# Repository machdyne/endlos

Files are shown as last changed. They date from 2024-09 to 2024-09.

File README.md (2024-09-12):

# Endlos Computer

Endlos is a 1-layer FPGA computer designed by Lone Dynamics Corporation.

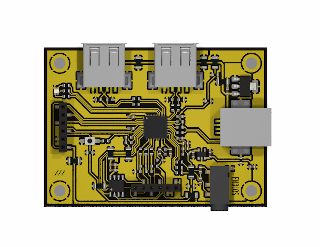
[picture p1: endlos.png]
Endlos Computer


This repo contains schematics, PCB layouts, pinouts, example gateware and documentation.

Find more information on the [Endlos product page](https://machdyne.com/product/endlos-computer/).

## Blinky 

Building the blinky example requires [Yosys](https://github.com/YosysHQ/yosys), [nextpnr-ice40](https://github.com/YosysHQ/nextpnr) and [IceStorm](https://github.com/YosysHQ/icestorm).

## Pinouts

### PMOD Socket (left, pins top-to-bottom)

| Pin | Signal | Description |
| ----| --- | --- |
| 1 | PMOD\_A1 | GPIO |
| 2 | PMOD\_A2 | GPIO |
| 3 | PMOD\_A3 | GPIO |
| 4 | PMOD\_A4 | GPIO |
| 5 | GND | Ground |
| 6 | 3V3 | Power |

### MMOD Socket (bottom, pins left-to-right)

| Pin | Signal | Description |
| --- | --- | --- |
| 1 | CSPI\_SS | GPIO |
| 2 | CSPI\_SO | GPIO |
| 3 | CSPI\_SI | GPIO |
| 4 | CSPI\_SCK | GPIO |
| 5 | GND | Ground |
| 6 | 3V3 | Power |

### Audio/Video Jack

| Pin | Description |
| --- | --- |
| T | Mono Audio |
| R1 | Mono Audio |
| R2 | Video |
| S | Ground |

## Board Revisions

| Revision | Notes |
| --- | ----- |
| V0 | Initial version |

Note #1: All of the functionality hasn't been tested yet, only configuration from MMOD and blinky on an LED PMOD.

Note #2: There should probably be a 10K pull-up on RAM\_SS, but configuration appears to work without it.

Note #3: Kapton tape is recommended under front of the USB-B connector.

## License

The contents of this repo are released under the [Lone Dynamics Open License](LICENSE.md).

Note: You can use these designs for commercial purposes but we ask that instead of producing exact clones, that you either replace our trademarks and logos with your own or add your own next to ours.

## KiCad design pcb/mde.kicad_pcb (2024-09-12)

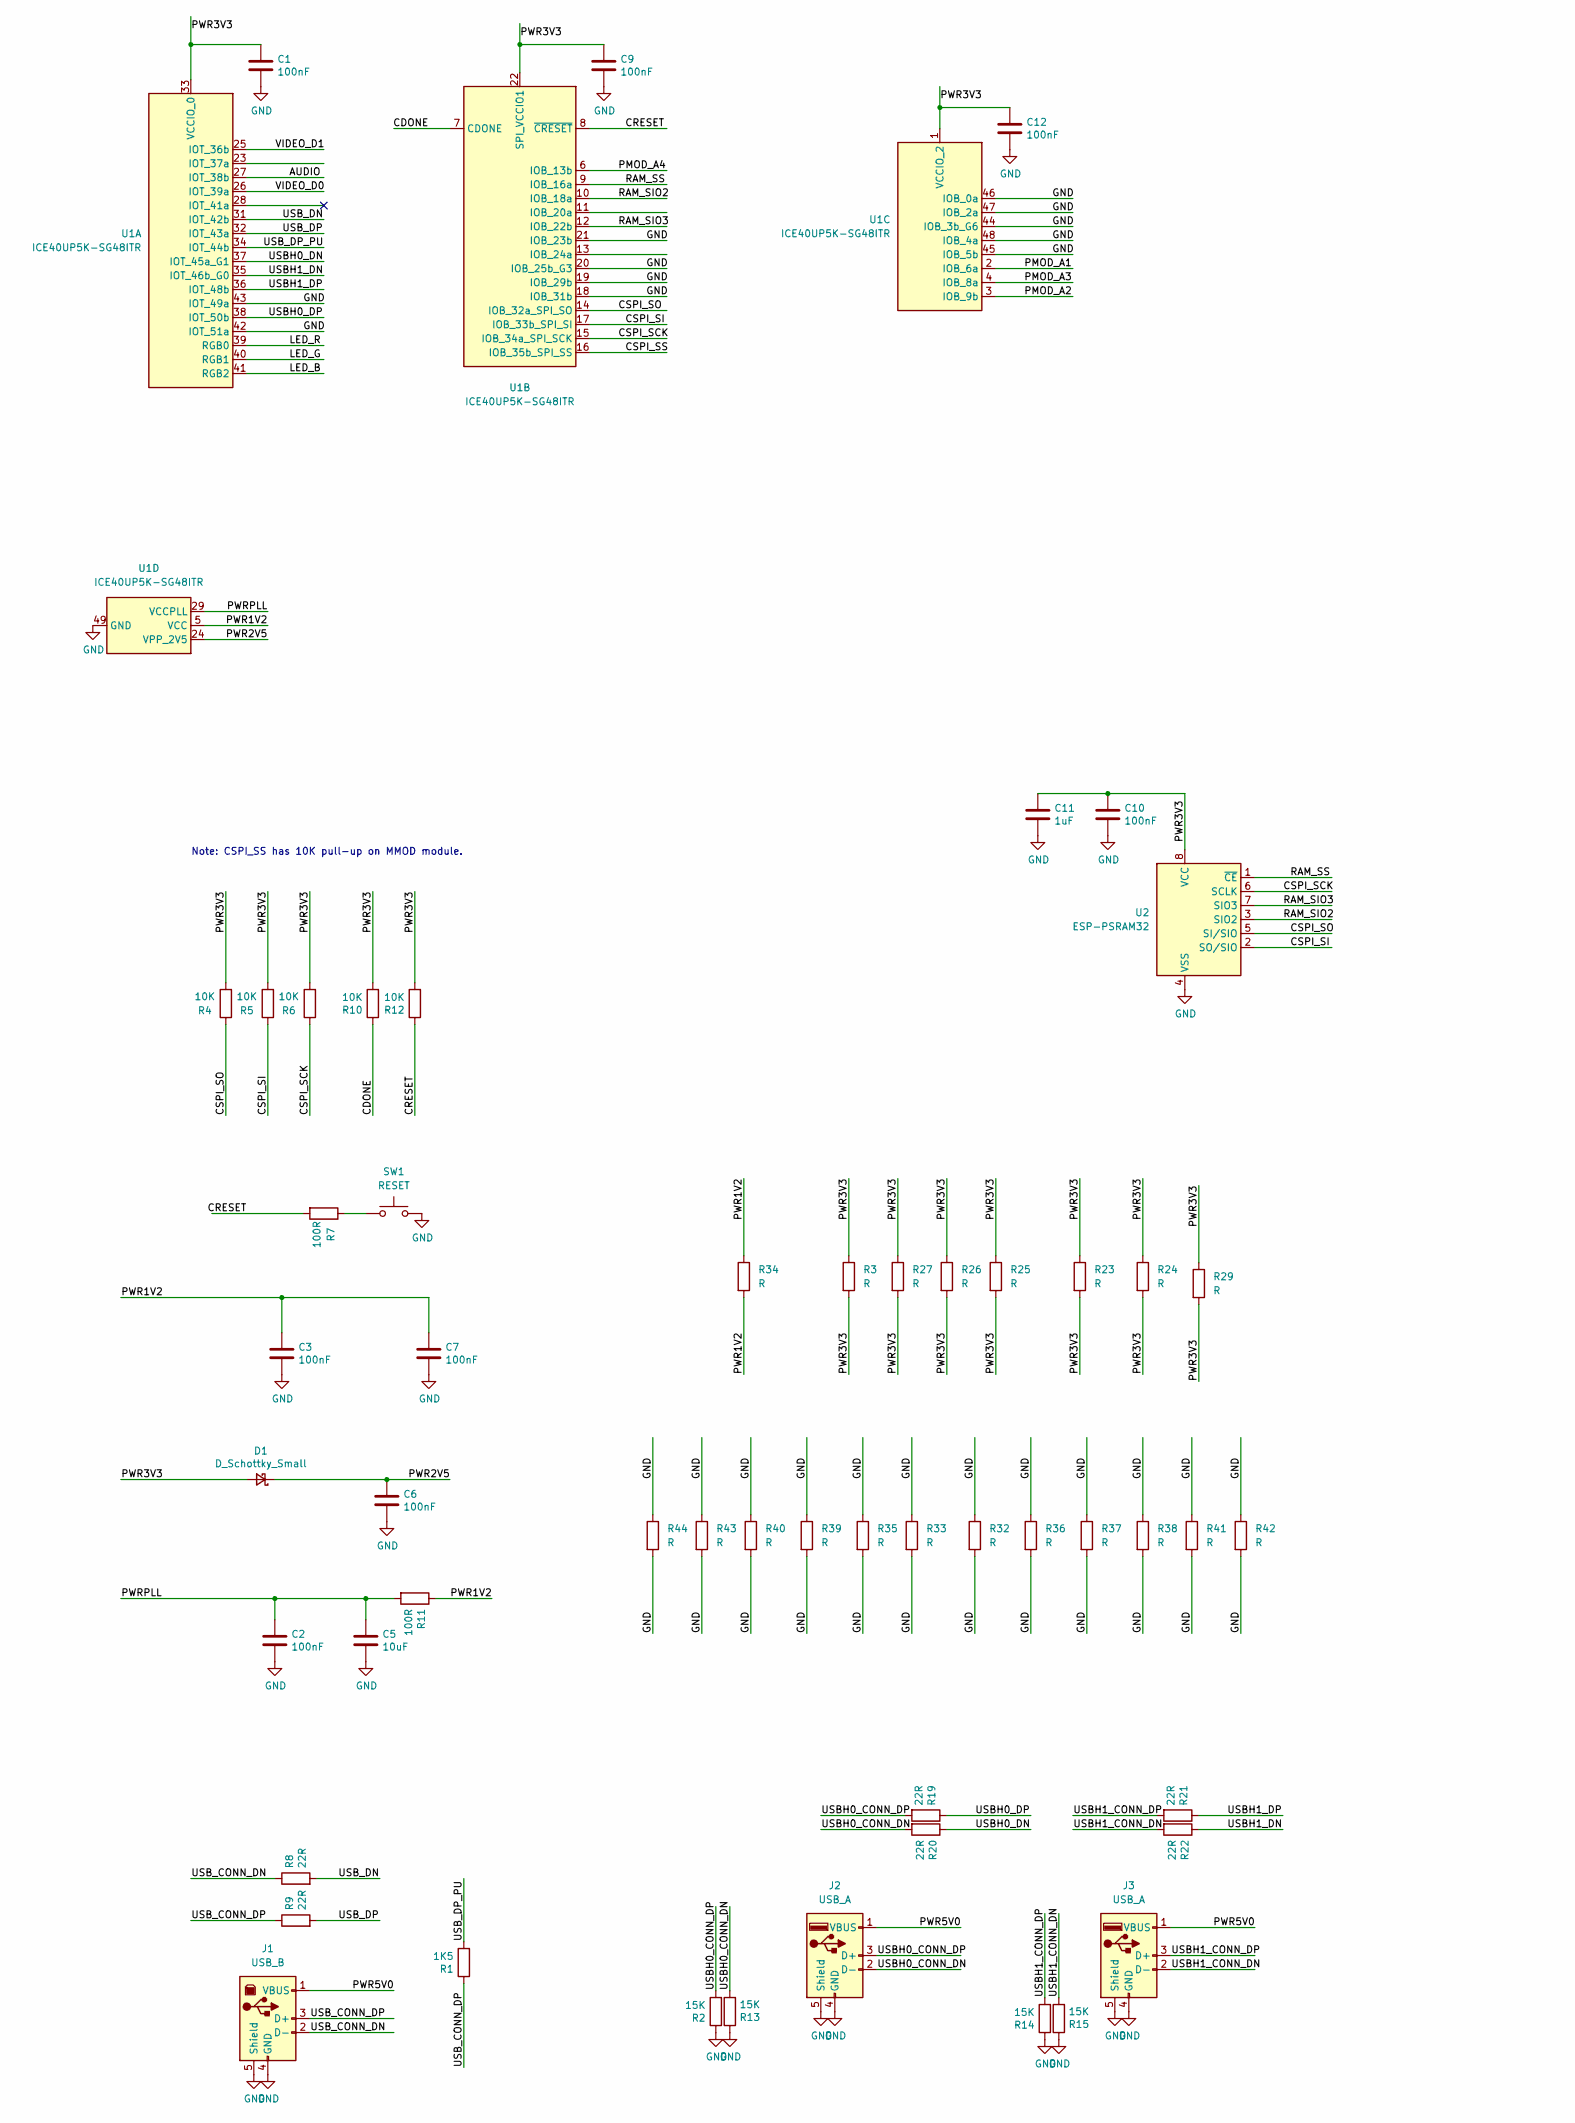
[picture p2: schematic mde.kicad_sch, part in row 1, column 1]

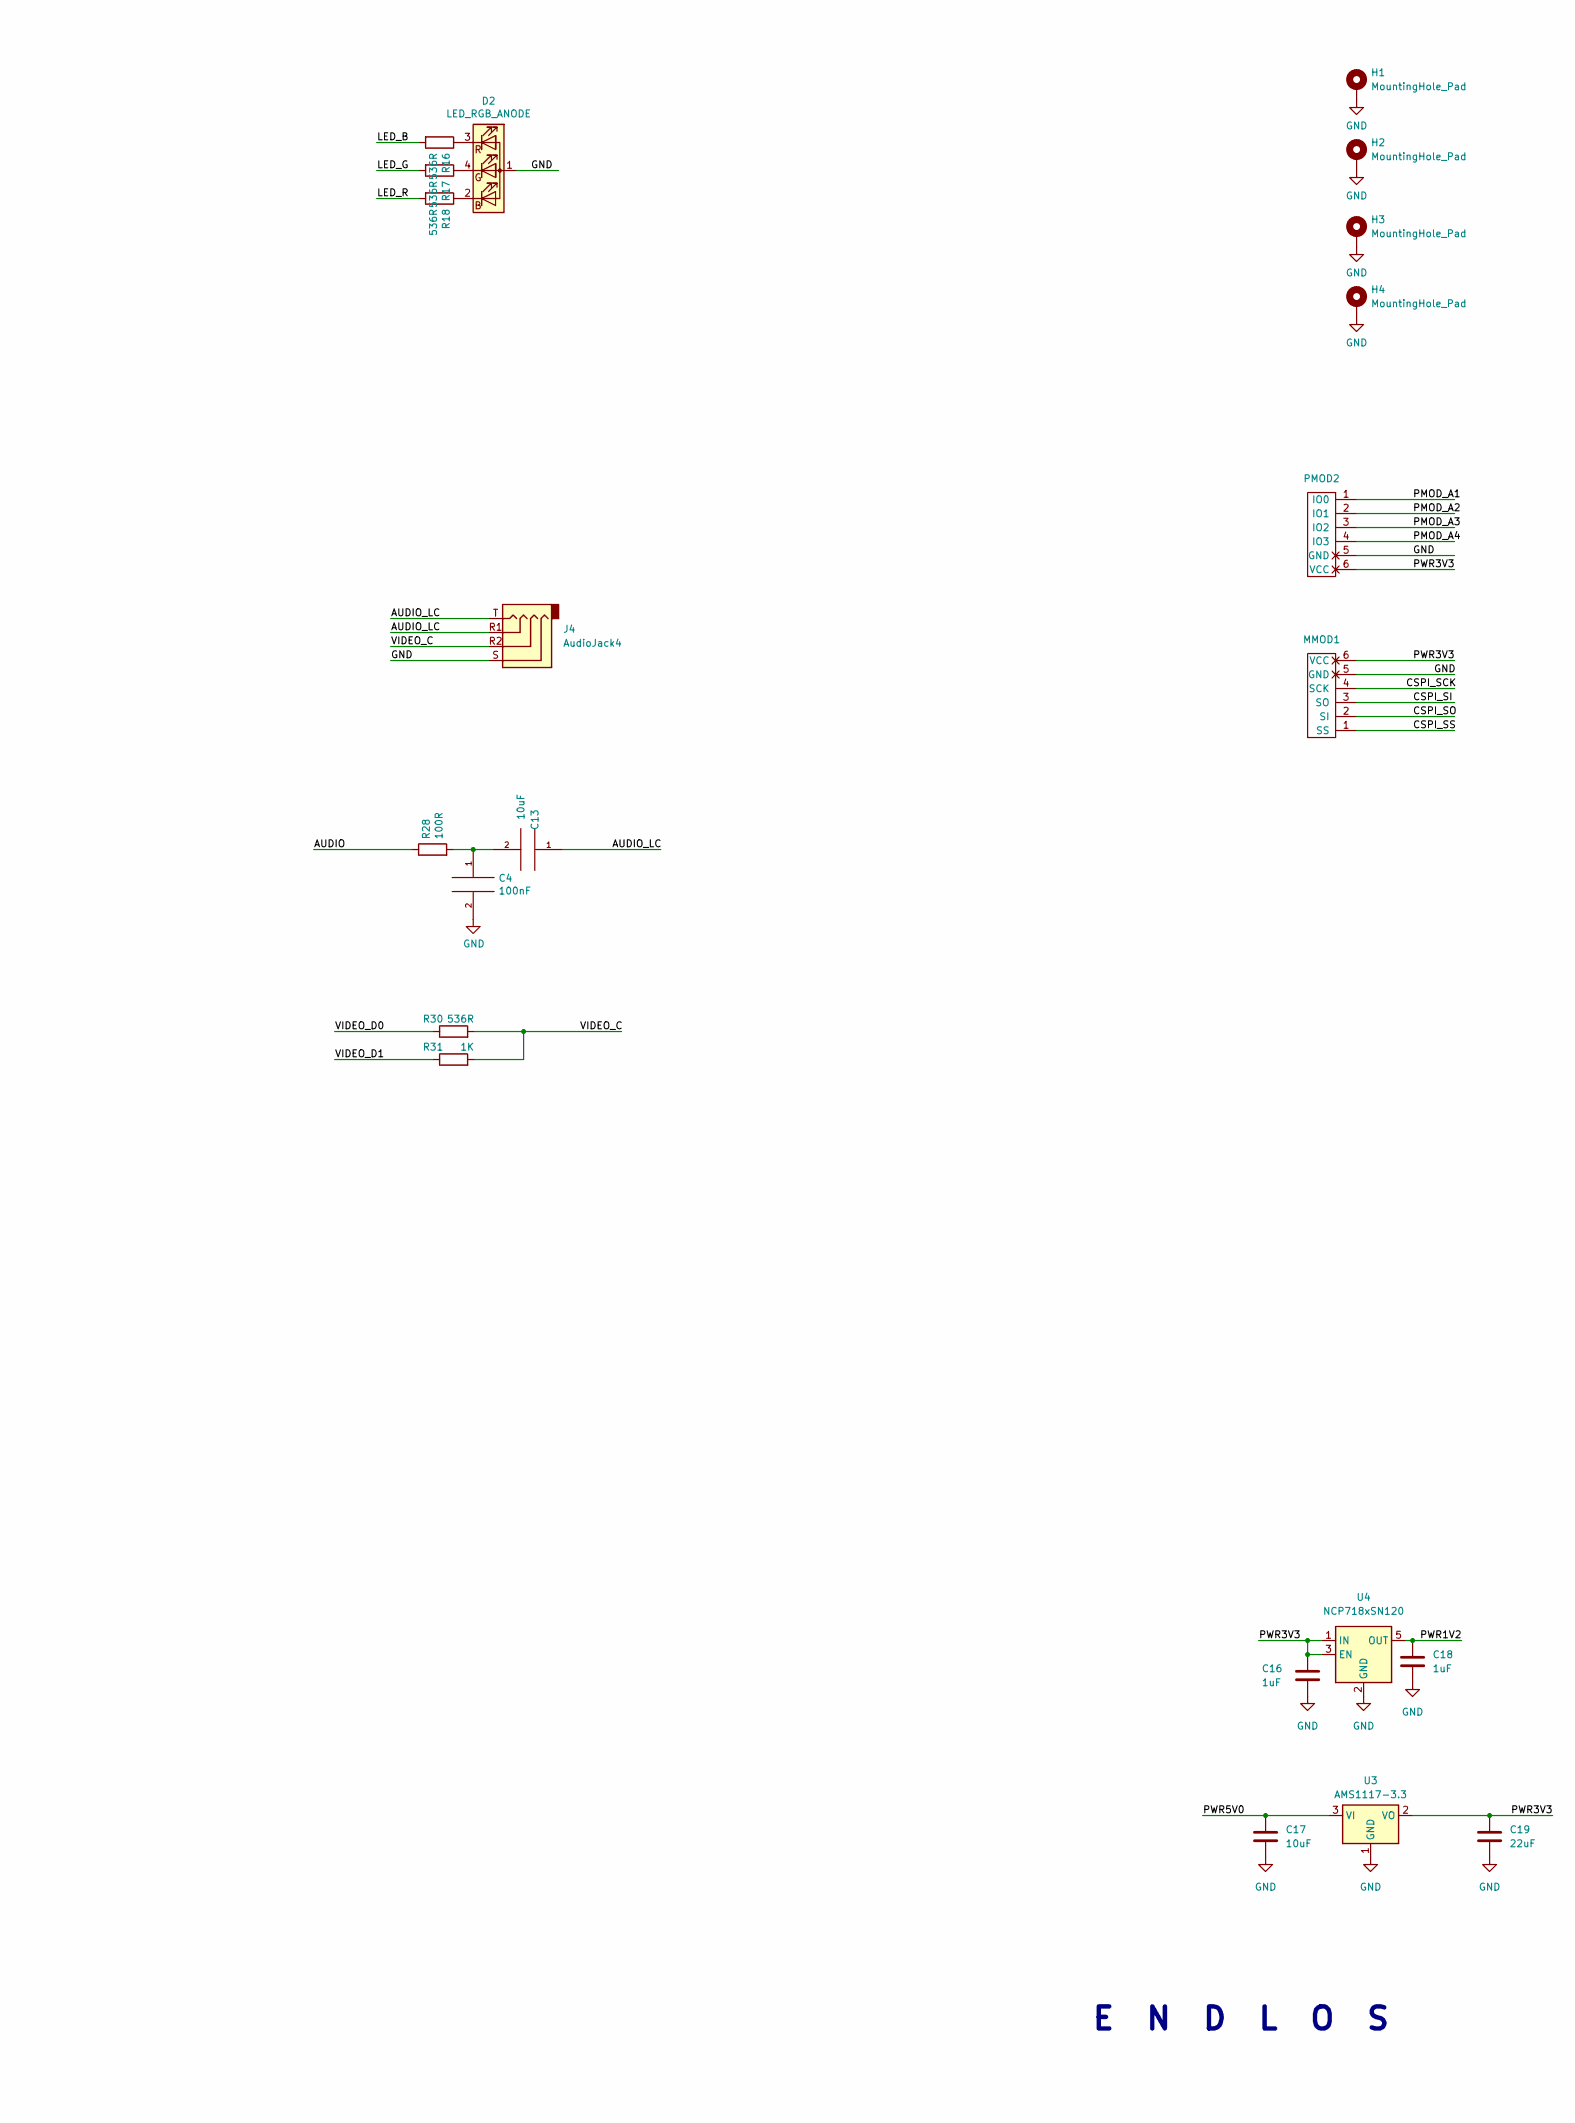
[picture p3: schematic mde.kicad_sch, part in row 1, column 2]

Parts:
C1, C2, C3, C4, C6, C7, C9, C10, C12: 100nF; C_0603_1608Metric
C5, C13, C17: 10uF; C_0603_1608Metric
C11, C16, C18: 1uF; C_0603_1608Metric
C19: 22uF; C_0603_1608Metric
D1: D_Schottky_Small; D_0603_1608Metric
D2: LED_RGB_ANODE; LED_RGB_0606_CHANZON
H1, H2, H3, H4: MountingHole_Pad; MountingHole_3.2mm_M3_ISO7380_Pad_TopOnly
J1: USB_B; SAMTEC_USB-B-S-X-X-SM-TR
J2, J3: USB_A; SAMTEC_USB-A-S-X-X-SM2
J4: AudioJack4; Jack_3.5mm_PJ320D_Horizontal
MMOD1: MMOD_Host_Socket; PinSocket_1x06_P2.54mm_Vertical_SMD_Pin1Left
PMOD2: PMOD-Host-x1-GPIO; PinSocket_1x06_P2.54mm_Vertical_SMD_Pin1Left
R1: 1K5; R_0603_1608Metric
R2, R13, R14, R15: 15K; R_0603_1608Metric
R3, R25, R26, R27, R33, R35, R39, R40, R43, R44: R; R_0603_1608Metric
R4, R5, R6, R10, R12: 10K; R_0603_1608Metric
R7, R11, R28: 100R; R_0603_1608Metric
R8, R9, R19, R20, R21, R22: 22R; R_0603_1608Metric
R16, R17, R18, R30: 536R; R_0603_1608Metric
R23, R24, R29, R32, R34, R36, R37, R38, R41, R42: R; R_1206_3216Metric
R31: 1K; R_0603_1608Metric
SW1: RESET; Button_2P_3x4mm
U1: ICE40UP5K-SG48ITR; QFN-48-1EP_7x7mm_P0.5mm_EP5.6x5.6mm
U2: ESP-PSRAM32; SOIC-8_3.9x4.9mm_P1.27mm
U3: AMS1117-3.3; SOT-223-3_TabPin2
U4: NCP718xSN120; SOT-23-5

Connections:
/AUDIO: R28.1, U1.27 (IOT_38b)
/AUDIO_LC: C13.1, J4.R1, J4.T
/CDONE: R10.1, U1.7 (CDONE)
/CRESET: R7.2, R12.1, U1.8 (~CRESET)
/CSPI_SCK: MMOD1.4 (SCK), R6.1, U1.15 (IOB_34a_SPI_SCK), U2.6 (SCLK)
/CSPI_SI: MMOD1.3 (SO), R5.1, U1.17 (IOB_33b_SPI_SI), U2.2 (SO/SIO)
/CSPI_SO: MMOD1.2 (SI), R4.1, U1.14 (IOB_32a_SPI_SO), U2.5 (SI/SIO)
/CSPI_SS: MMOD1.1 (SS), U1.16 (IOB_35b_SPI_SS)
/LED_B: R16.2, U1.41 (RGB2)
/LED_G: R17.2, U1.40 (RGB1)
/LED_R: R18.2, U1.39 (RGB0)
/PMOD_A1: PMOD2.1 (IO0), U1.2 (IOB_6a)
/PMOD_A2: PMOD2.2 (IO1), U1.3 (IOB_9b)
/PMOD_A3: PMOD2.3 (IO2), U1.4 (IOB_8a)
/PMOD_A4: PMOD2.4 (IO3), U1.6 (IOB_13b)
/PWR1V2: C3.1, C7.1, C18.1, R11.1, R34.1, R34.2, U1.5 (VCC), U1.30 (VCC), U4.5 (OUT)
/PWR2V5: C6.1, D1.1 (K), U1.24 (VPP_2V5)
/PWR3V3: C1.1, C9.1, C10.1, C11.1, C12.1, C16.1, C19.1, D1.2 (A), MMOD1.6 (VCC), PMOD2.6 (VCC), R3.1, R3.2, R4.2, R5.2, R6.2, R10.2, R12.2, R23.1, R23.2, R24.1, R24.2, R25.1, R25.2, R26.1, R26.2, R27.1, R27.2, R29.1, R29.2, U1.1 (VCCIO_2), U1.22 (SPI_VCCIO1), U1.33 (VCCIO_0), U2.8 (VCC), U3.2 (VO), U4.1 (IN), U4.3 (EN)
/PWR5V0: C17.1, J1.1 (VBUS), J2.1 (VBUS), J3.1 (VBUS), U3.3 (VI)
/PWRPLL: C2.1, C5.1, R11.2, U1.29 (VCCPLL)
/RAM_SIO2: U1.10 (IOB_18a), U2.3 (SIO2)
/RAM_SIO3: U1.12 (IOB_22b), U2.7 (SIO3)
/RAM_SS: U1.9 (IOB_16a), U2.1 (~CE)
/USBH0_CONN_DN: J2.2 (D-), R13.2, R20.2
/USBH0_CONN_DP: J2.3 (D+), R2.2, R19.2
/USBH0_DN: R20.1, U1.37 (IOT_45a_G1)
/USBH0_DP: R19.1, U1.38 (IOT_50b)
/USBH1_CONN_DN: J3.2 (D-), R15.2, R22.2
/USBH1_CONN_DP: J3.3 (D+), R14.2, R21.2
/USBH1_DN: R22.1, U1.35 (IOT_46b_G0)
/USBH1_DP: R21.1, U1.36 (IOT_48b)
/USB_CONN_DN: J1.2 (D-), R8.1
/USB_CONN_DP: J1.3 (D+), R1.1, R9.1
/USB_DN: R8.2, U1.31 (IOT_42b)
/USB_DP: R9.2, U1.32 (IOT_43a)
/USB_DP_PU: R1.2, U1.34 (IOT_44b)
/VIDEO_C: J4.R2, R30.2, R31.2
/VIDEO_D0: R30.1, U1.26 (IOT_39a)
/VIDEO_D1: R31.1, U1.25 (IOT_36b)
GND: C1.2, C2.2, C3.2, C4.2, C5.2, C6.2, C7.2, C9.2, C10.2, C11.2, C12.2, C16.2, C17.2, C18.2, C19.2, D2.1 (A), H1.1, H2.1, H3.1, H4.1, J1.4 (GND), J1.5 (Shield), J2.4 (GND), J2.5 (Shield), J3.4 (GND), J3.5 (Shield), J4.S, MMOD1.5 (GND), PMOD2.5 (GND), R2.1, R13.1, R14.1, R15.1, R32.1, R32.2, R33.1, R33.2, R35.1, R35.2, R36.1, R36.2, R37.1, R37.2, R38.1, R38.2, R39.1, R39.2, R40.1, R40.2, R41.1, R41.2, R42.1, R42.2, R43.1, R43.2, R44.1, R44.2, SW1.2, U1.18 (IOB_31b), U1.19 (IOB_29b), U1.20 (IOB_25b_G3), U1.21 (IOB_23b), U1.42 (IOT_51a), U1.43 (IOT_49a), U1.44 (IOB_3b_G6), U1.45 (IOB_5b), U1.46 (IOB_0a), U1.47 (IOB_2a), U1.48 (IOB_4a), U1.49 (GND), U2.4 (VSS), U3.1 (GND), U4.2 (GND)
unnamed: C4.1, C13.2, R28.2
unnamed: D2.2 (BK), R18.1
unnamed: D2.4 (GK), R17.1
unnamed: D2.3 (RK), R16.1
unnamed: R7.1, SW1.1

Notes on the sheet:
E N D L O S
Note: CSPI_SS has 10K pull-up on MMOD module.

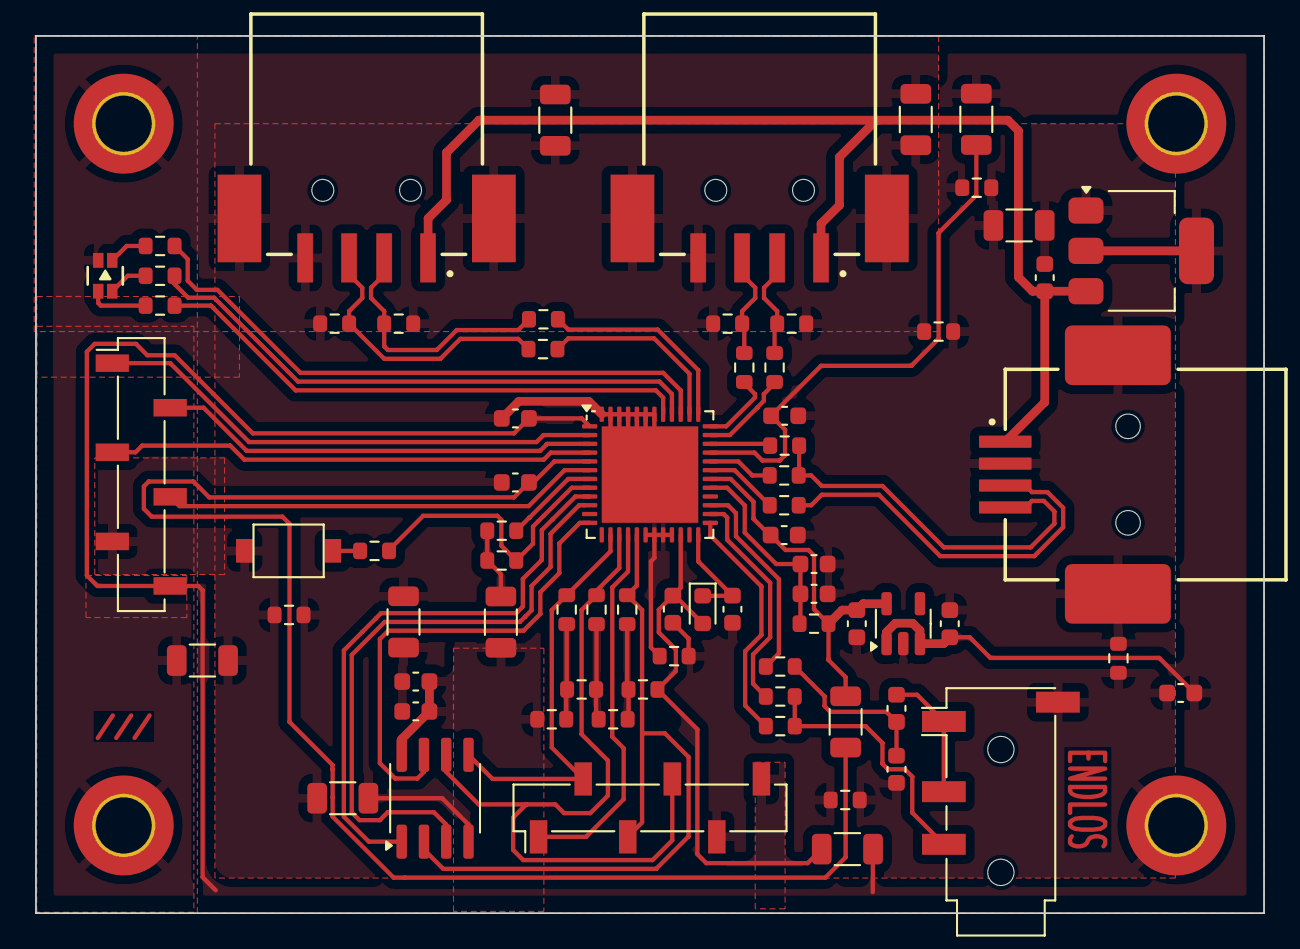
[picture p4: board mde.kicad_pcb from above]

Board: 2 copper layers, 70.0 x 50.0 mm, 77 parts (0 on the bottom side), 45 nets.

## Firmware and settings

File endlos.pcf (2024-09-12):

# Endlos V0
# ---------

# RGB LED
set_io LED_R	40
set_io LED_G	41
set_io LED_B	39

# PMOD_A
set_io PMOD_A1		2
set_io PMOD_A2		3
set_io PMOD_A3		4
set_io PMOD_A4		6
